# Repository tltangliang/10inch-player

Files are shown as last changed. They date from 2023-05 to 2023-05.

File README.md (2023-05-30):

# 10inch-player

A 10 inch width HiFi music player with 7.84 touchscreen.

## Features

- Simple and clear design
- Easy to use
- Hi-Res DSD support
- AirPlay and Bluetooth support
- Low cost
- Low power use

## Introduction

I have an old set of Denon speakers that can only play CDs and tapes, which is outdated. This has inspired me to come up with an idea. 

I plan to use Volumio as a digital playback system and hope that the appearance is as good-looking as possible, while keeping the cost low.

Volumio support AirPlay and Bluetooth. That's perfect. Alternatively, I can use piCorePlayer or Moode Audio Player instead.

This is the effect of placing the DIY finished product next to the Denon speaker. It looks pretty durable, doesn't it?

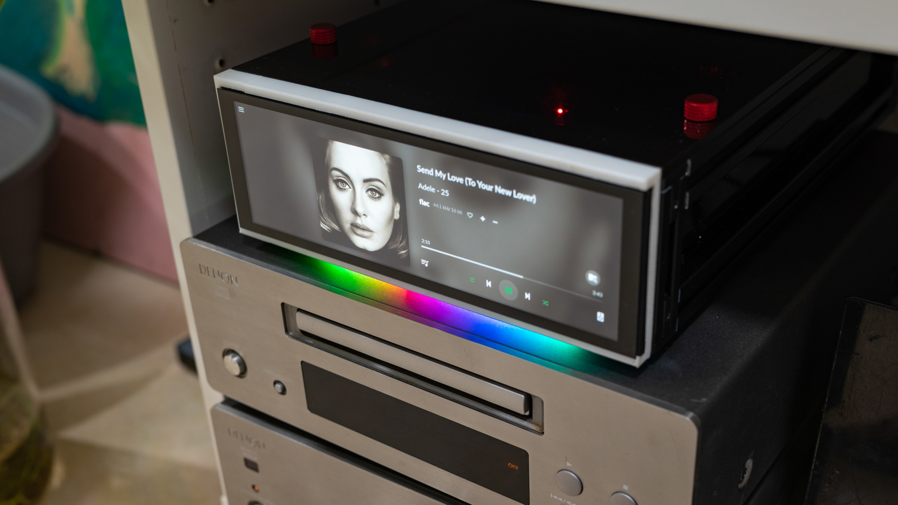
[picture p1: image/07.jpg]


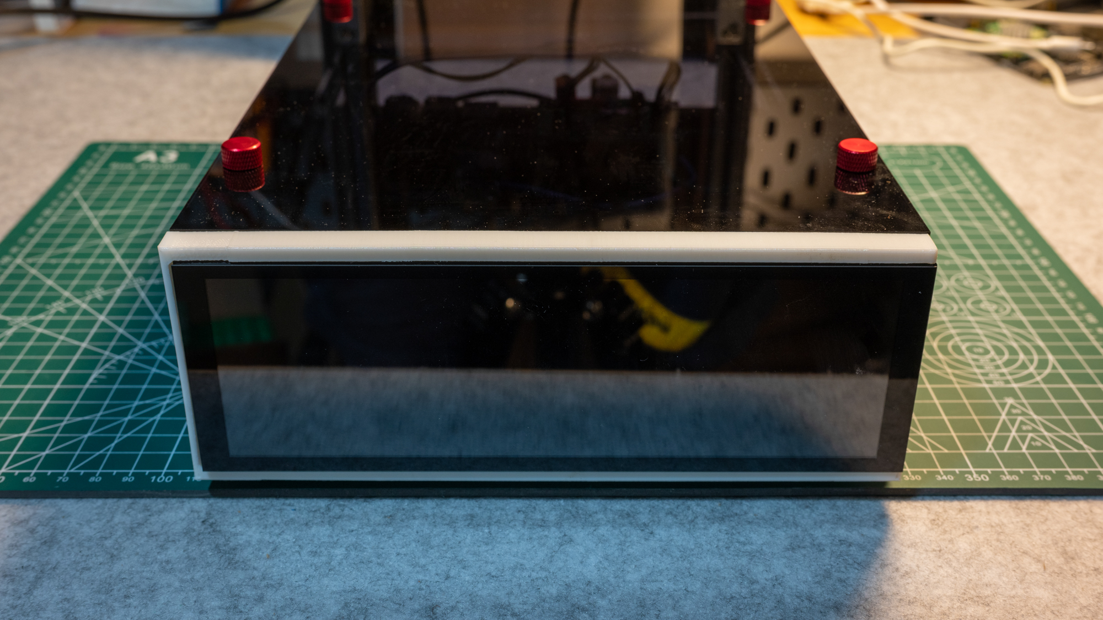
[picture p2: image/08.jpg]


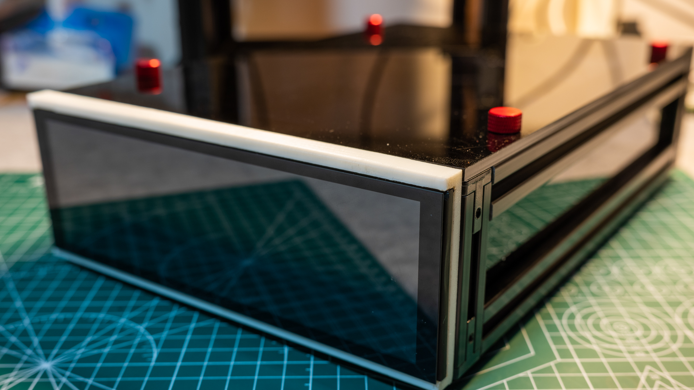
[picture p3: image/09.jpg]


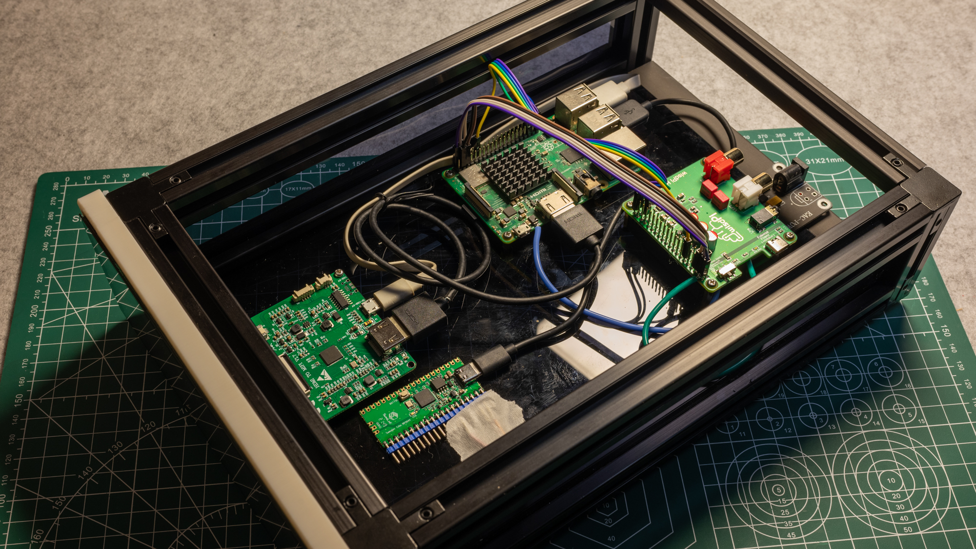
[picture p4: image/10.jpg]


## System Description

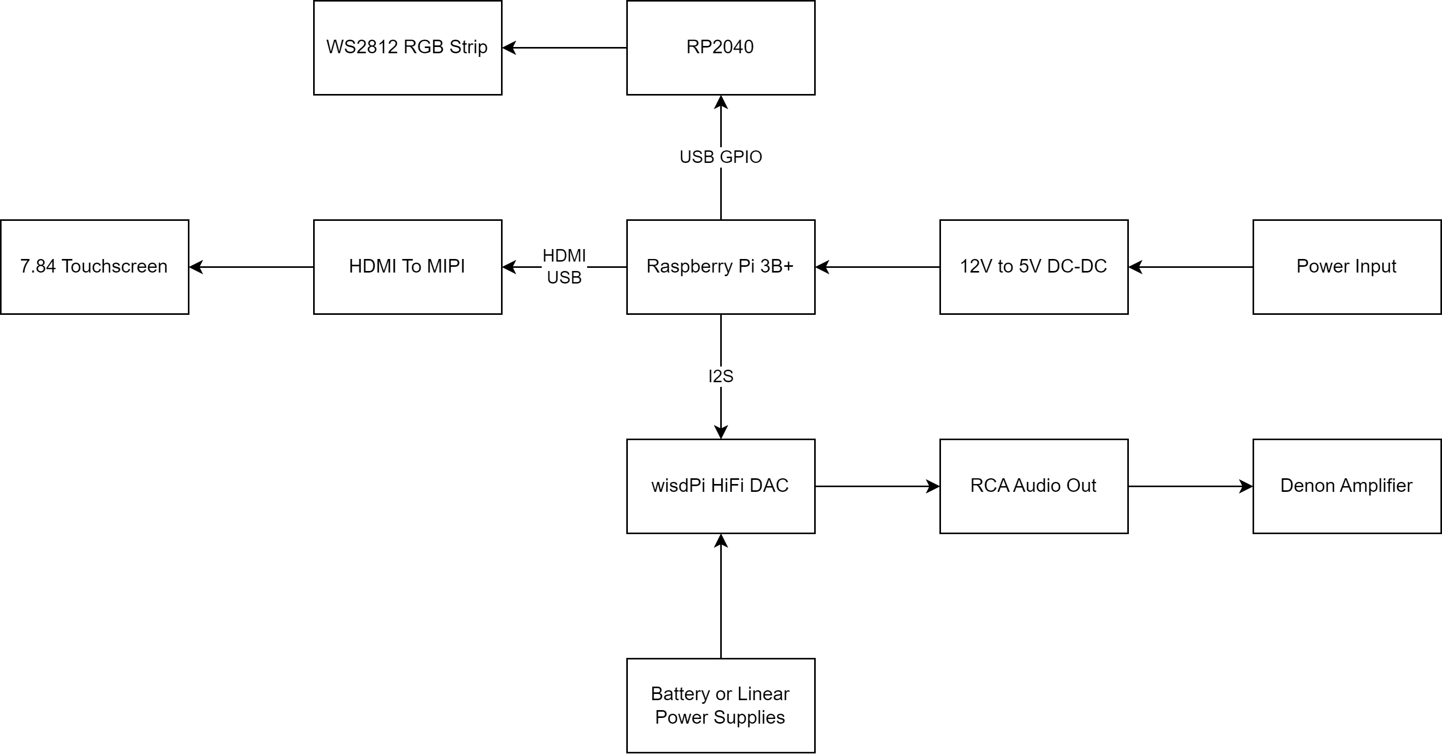
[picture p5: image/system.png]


## Rendering

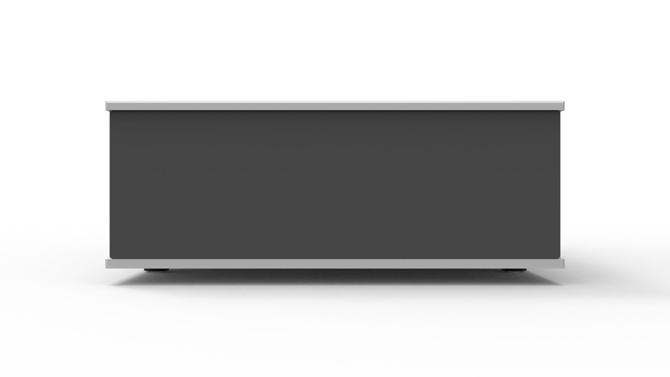
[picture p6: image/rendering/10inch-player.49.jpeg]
10inch HiFi Player :size=400x


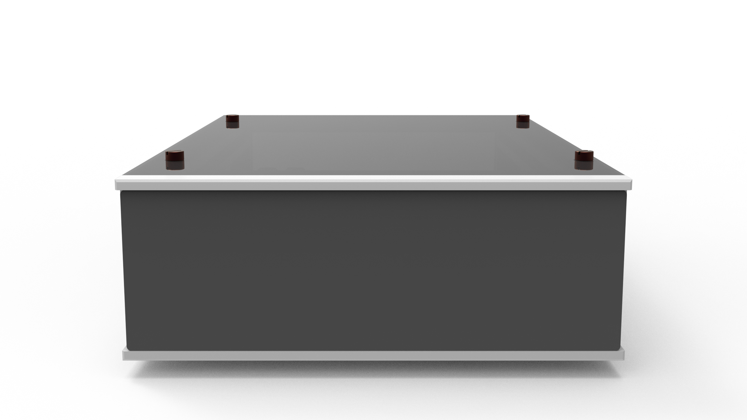
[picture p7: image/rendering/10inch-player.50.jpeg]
10inch HiFi Player :size=400x


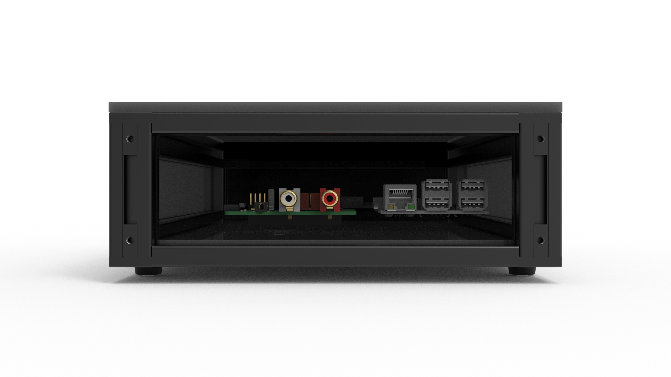
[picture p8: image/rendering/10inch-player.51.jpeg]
10inch HiFi Player :size=400x


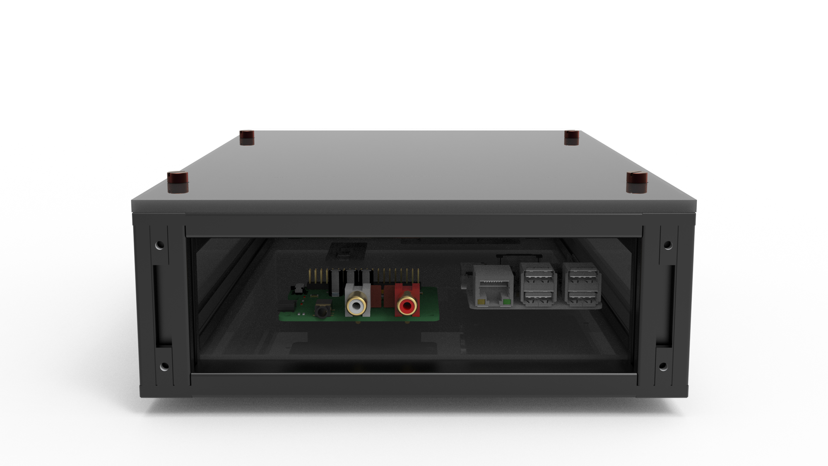
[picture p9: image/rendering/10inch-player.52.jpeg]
10inch HiFi Player :size=400x


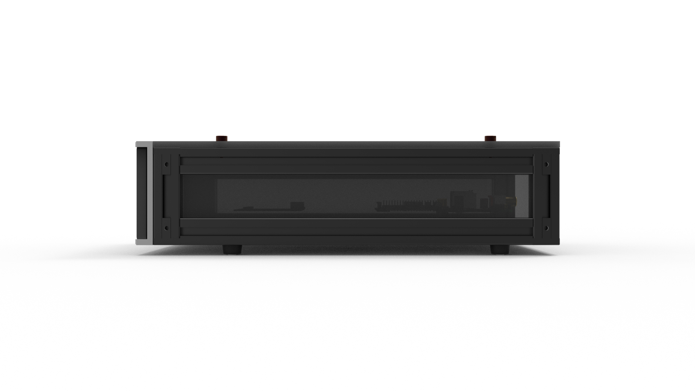
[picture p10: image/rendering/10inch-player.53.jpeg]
10inch HiFi Player :size=400x


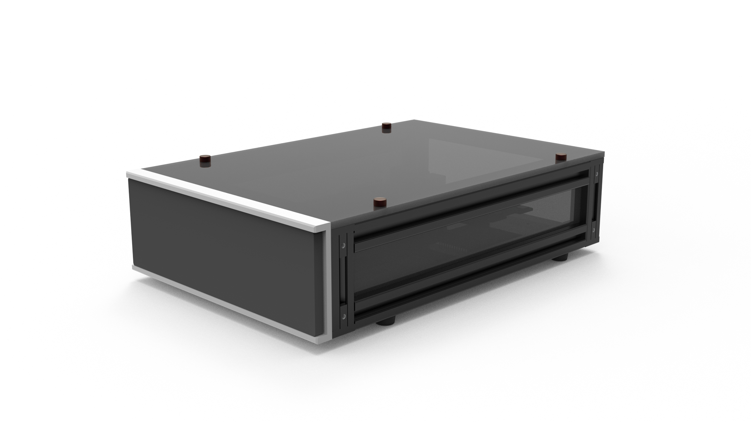
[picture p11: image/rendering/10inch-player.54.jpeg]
10inch HiFi Player :size=400x


## Case

The 10inch-Player case is made up of three materials: aluminum profile, acrylic, and 3D printed parts, along with some screws and foot pads.

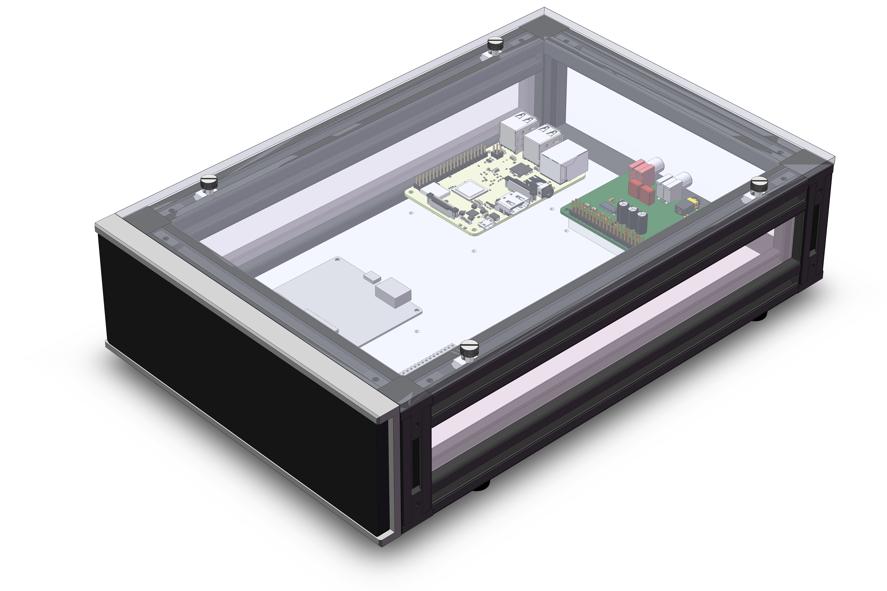
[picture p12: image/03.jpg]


## Exploded-view

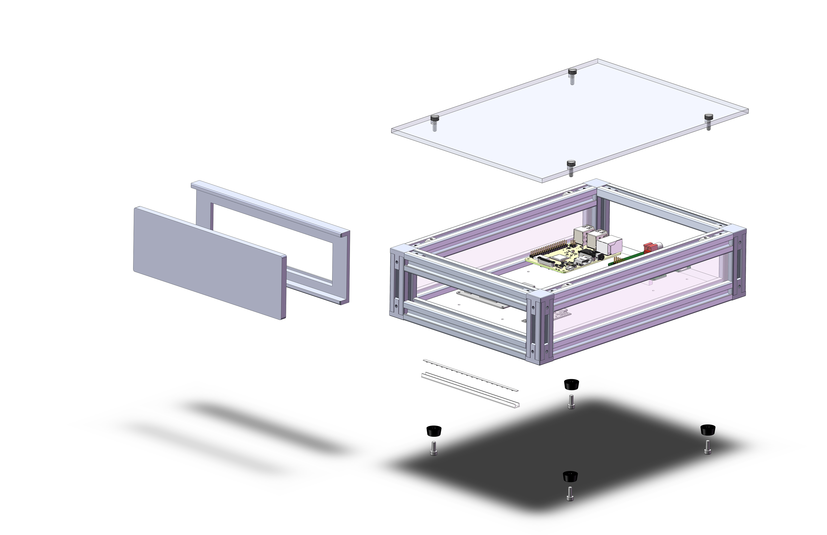
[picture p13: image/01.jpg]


## 7.84 Touchscreen

Purchase Link: [https://store.wisdpi.com/products/7-84inch-ips-long-strip-capacitive-touch-screen-lcd-400-1280-hdmi-ips-toughened-glass-cover-support-raspberry-pi](https://store.wisdpi.com/products/7-84inch-ips-long-strip-capacitive-touch-screen-lcd-400-1280-hdmi-ips-toughened-glass-cover-support-raspberry-pi)

At first I wanted to choose the waveshare screen, but then I found that the waveshare screen was not suitable for this structure and could not be used. Then I found this touchscreen from wisdPi. They use the same software. And this screen panel and driver board is independent, more suitable for diy installation

The 7.84-inch touch screen is glued to the 3D-printed bracket and then slid into the aluminum profile for fixation.

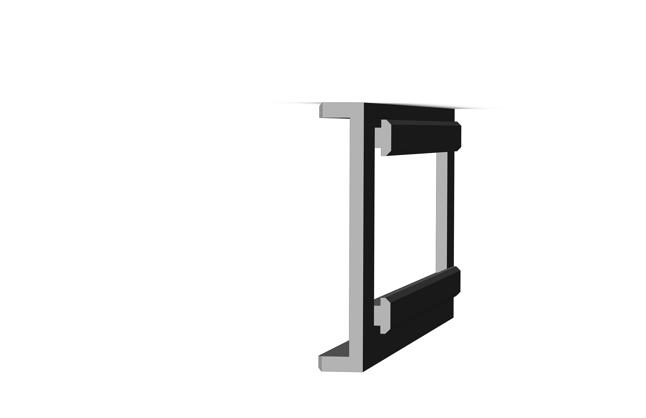
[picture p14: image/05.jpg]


## Internal circuit board

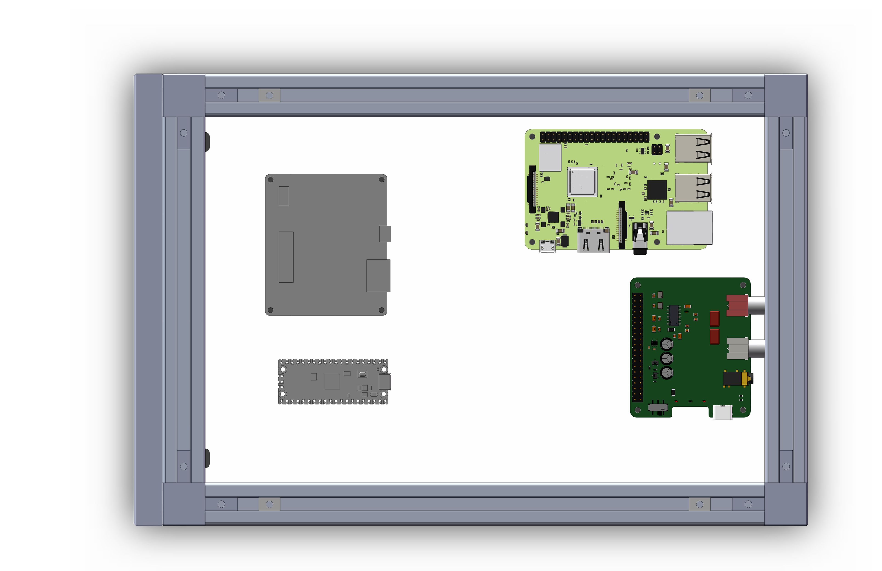
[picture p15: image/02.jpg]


### HDMI to MIPI board

This is the driver board for 7.84 LCD. It's a part of 7.84 Touchscreen.

### Raspberry Pi 3B+
For Volumio, I think RPi 3B+ is more suitable because it is much cheaper, has sufficient performance, and supports Bluetooth and 5G Wifi.

### wisdPi HiFi DAC 

Purchase Link: [https://www.amazon.com/wisdPi-Raspberry-PCM5122-Reduction-External/dp/B0C3CMCM7V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](https://www.amazon.com/wisdPi-Raspberry-PCM5122-Reduction-External/dp/B0C3CMCM7V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)

There are many HiFi DACs, but I choose the one from wisdPi.

This HAT has an active power noise reduction function, and I can use a cheaper power adapter.

Also it has an external power interface, next I will try to use a low power linear power supply to power the dac alone, which is cheaper than using a linear power supply to power the whole system. Also I can try to power the DAC directly with a battery.

### Sumolink Erhu RP2040

Purchase Link: [https://www.temu.com/sumolink-erhu-rp2040-pico-like-mcu-board-based-on-raspberry-pi-rp2040-chip-dual-core-arm-cortex-m0-processor-up-to-133-mhz-onboard-4mb-flash-usb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](https://www.temu.com/sumolink-erhu-rp2040-pico-like-mcu-board-based-on-raspberry-pi-rp2040-chip-dual-core-arm-cortex-m0-processor-up-to-133-mhz-onboard-4mb-flash-usb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)

To control WS2812 RGB strip and the power next step, I use an rp2040 mcu.

I used the rp2040 instead of the Raspberry Pi gpio because it was difficult for me to modify the volumio. And using an external mcu gives me more freedom and I can control more devices, such as the LCD brightness, RPi power on or power off.

Just because the price, I choose Sumolink Erhu RP2040, you can use any rp2040 mcu board as the same.

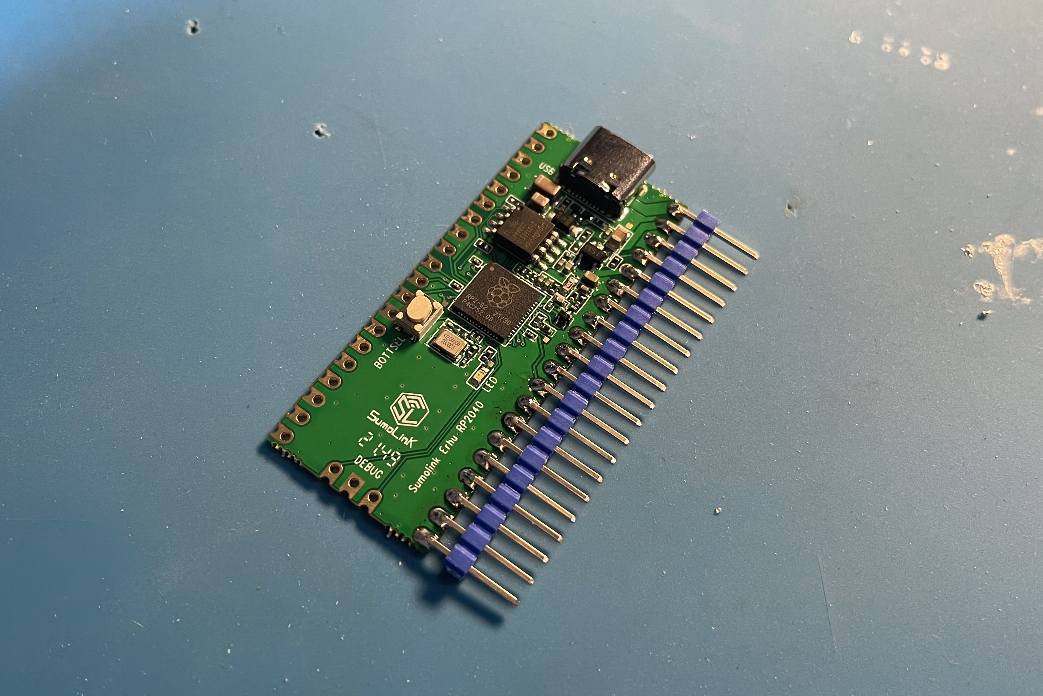
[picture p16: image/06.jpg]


# Buy me a coffee

If you find my projects helpful or interesting, could you buy me a coffee. Your support will help me continue creating new and innovative projects, as well as provide exclusive access to my content.

Buy Me A Coffee :size=50x (https://www.buymeacoffee.com/tltangliang)

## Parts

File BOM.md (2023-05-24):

# 7.84 Touchcreen Player BOM

| Title | Parameter | Quantity | |
| --- | --- | --- | --- |
| aluminum extrusion 260mm | 2020T Black  | 4 | |
| aluminum extrusion 62mm| 2020T Black | 4 | |
| aluminum extrusion 170mm | 2020T Black | 2 | |
| aluminum extrusion 170mm | 1020V Black | 2 | |
| aluminum extrusion connection | 2020 3D | 8 | |
| acrylic top | Thickness 5 mm | 1 | |
| acrylic bottom | Thickness 5 mm | 1 | |
| acrylic side | Thickness 5 mm | 2 | |
| sider nut | 2020 M4| 8 | |
| aluminum knurled screws | M4 x 12mm Dark Red | 4 | |
| rubber feet | 15-13-7 M4 | 4 | |
| rubber feet screws |  M4 x 10mm | 4 | |
| LCD mount | 3D print | 1 | |
| LCD 7.84 Touch | 400x1280 IPS  | 1 | |
| LCD driver board | HDMI to MIPI | 1 | |
| HiFi DAC HAT | wisdPi HiFi DAC | 1 | |
| MCU | Sumolink Erhu RP2040 | 1 | |
| RGB strip | WS28128 3MM 100LEDS/m 13cm long | 1 | |
| DC-DC Module | 12V to 5V | 1 | optional |
| Raspberry Pi | Pi 3B+ | 1 | |

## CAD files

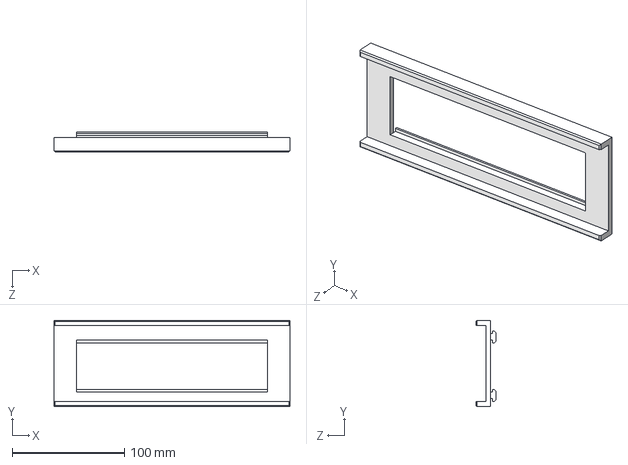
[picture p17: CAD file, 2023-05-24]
01.structure/3D print LCD mount/LCD mount.STEP
210.0 x 76.7 x 17.9 mm

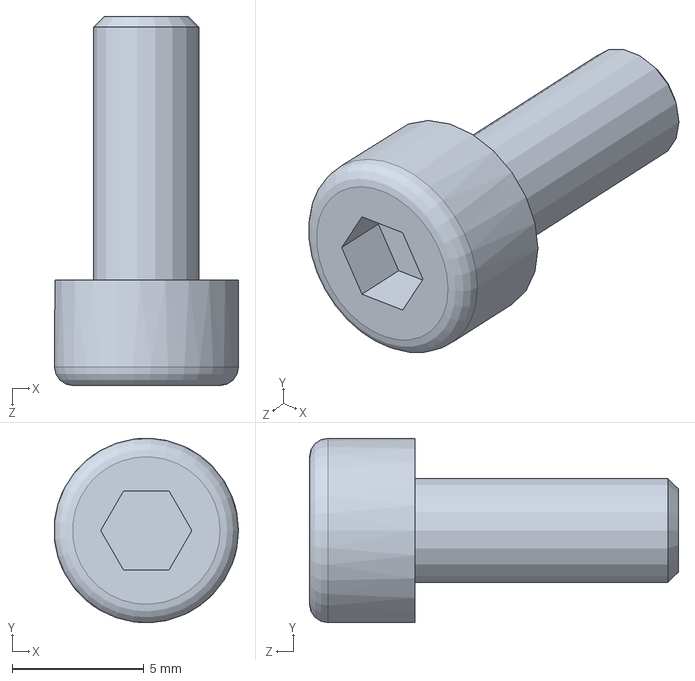
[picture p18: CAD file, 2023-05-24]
01.structure/M4 x 10 srew.SLDPRT
6.98 x 6.99 x 14.0 mm

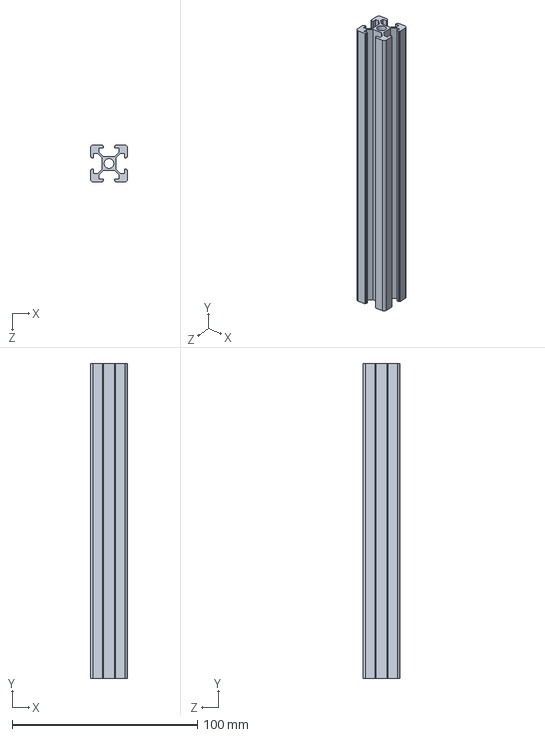
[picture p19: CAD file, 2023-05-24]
01.structure/2020 W 170mm.SLDPRT
20.0 x 170.0 x 20.0 mm

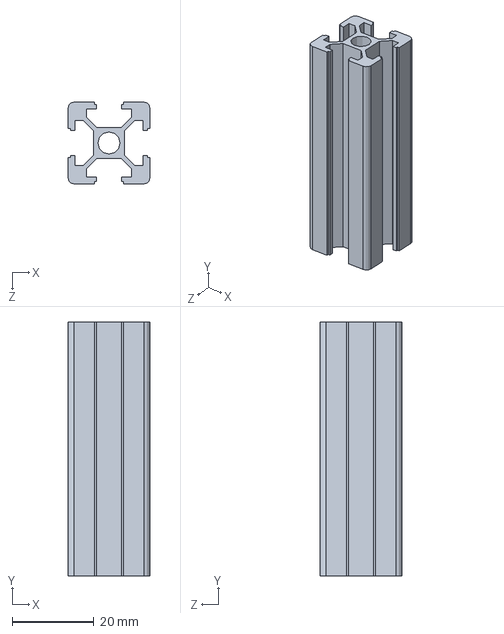
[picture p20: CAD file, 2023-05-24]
01.structure/2020 H 62mm.SLDPRT
20.0 x 62.0 x 20.0 mm

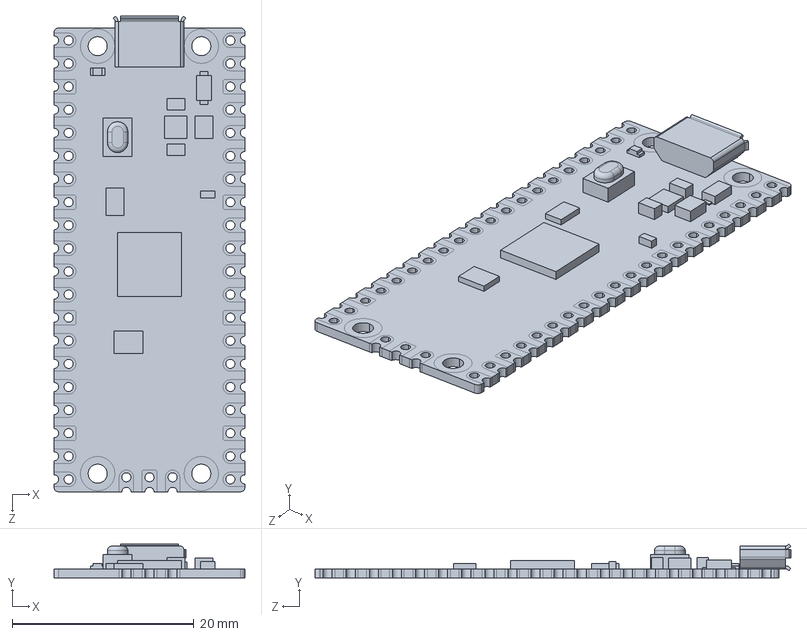
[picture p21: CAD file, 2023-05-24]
01.structure/RPI Pico-R3.SLDPRT
21.0 x 3.73 x 52.3 mm

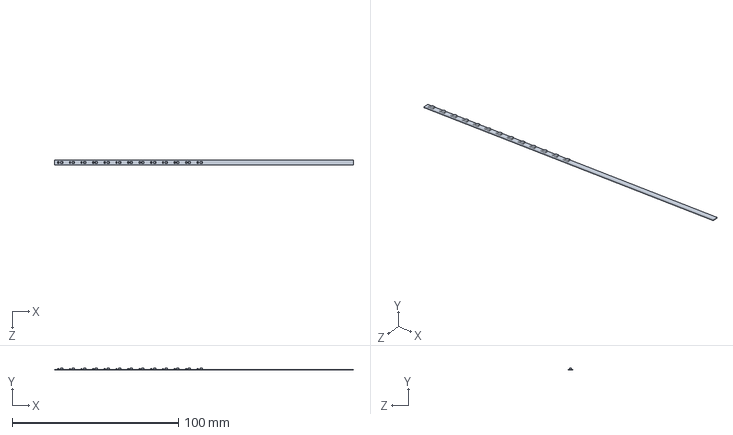
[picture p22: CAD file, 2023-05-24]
01.structure/3mm RGB Strip.SLDPRT
180.0 x 1.50 x 3.00 mm

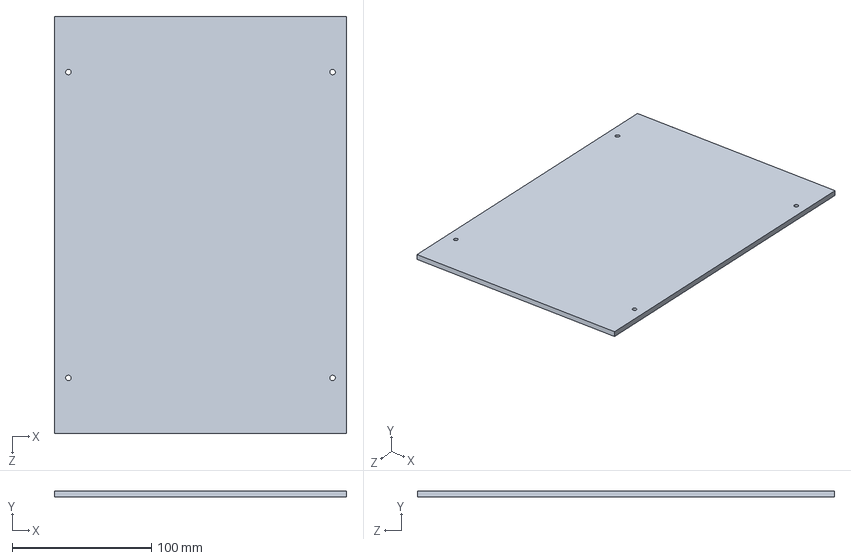
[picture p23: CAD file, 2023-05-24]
01.structure/acrylic top.SLDPRT
210.0 x 4.65 x 300.0 mm

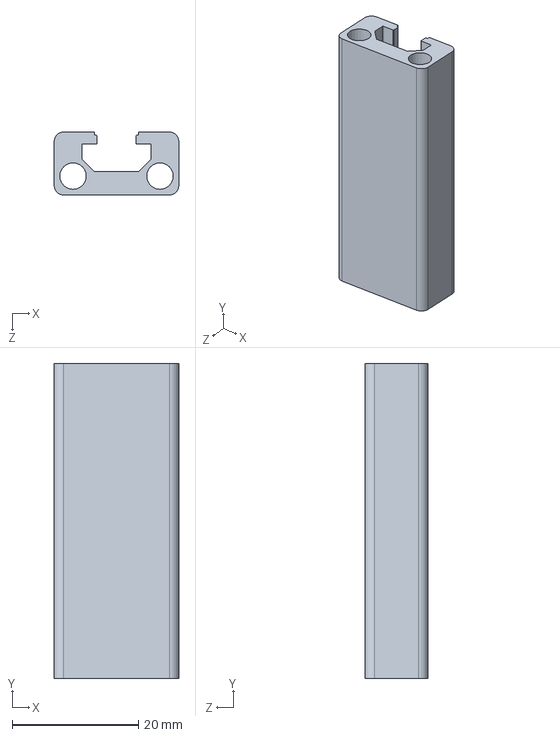
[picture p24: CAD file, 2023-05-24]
01.structure/1020 W 170mm.SLDPRT
19.8 x 50.0 x 10.0 mm

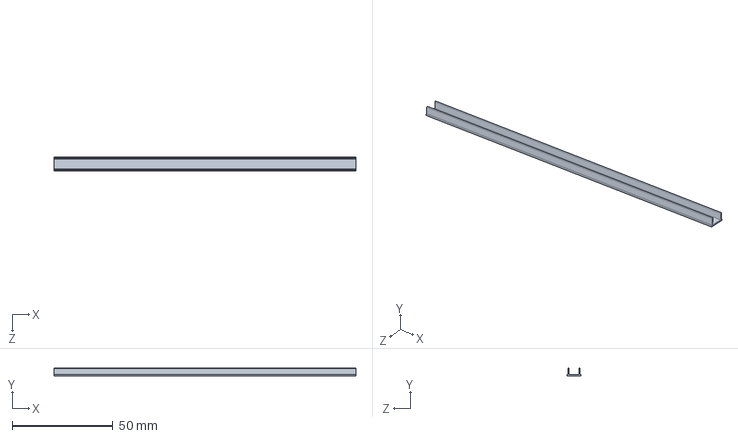
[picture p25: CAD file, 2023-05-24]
01.structure/semi-transparent Hard rubber strip 130mm.SLDPRT
150.0 x 4.00 x 7.00 mm

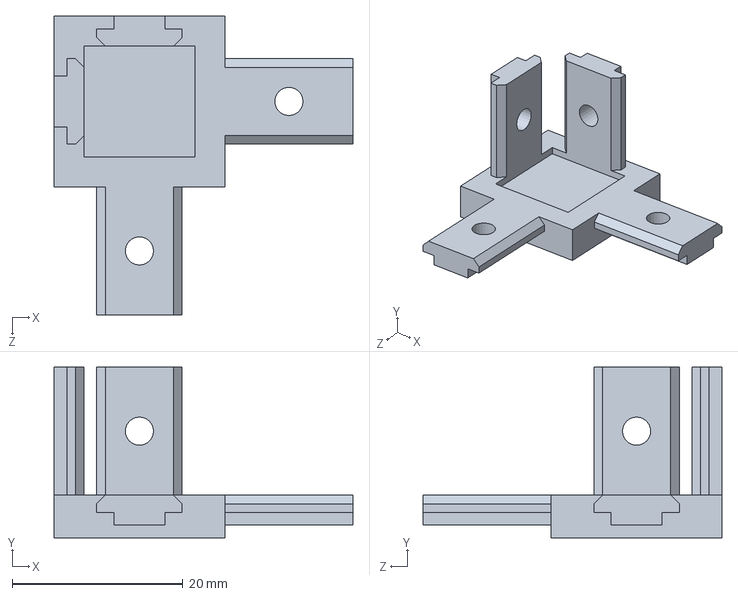
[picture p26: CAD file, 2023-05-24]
01.structure/2020 3D connection.SLDPRT
35.0 x 20.0 x 35.0 mm

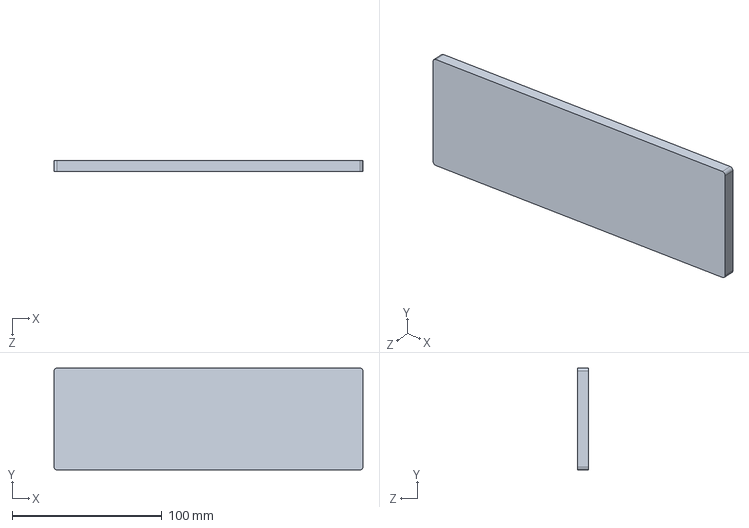
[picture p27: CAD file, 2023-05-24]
01.structure/LCD 7.84 IPS.SLDPRT
206.0 x 68.0 x 7.00 mm

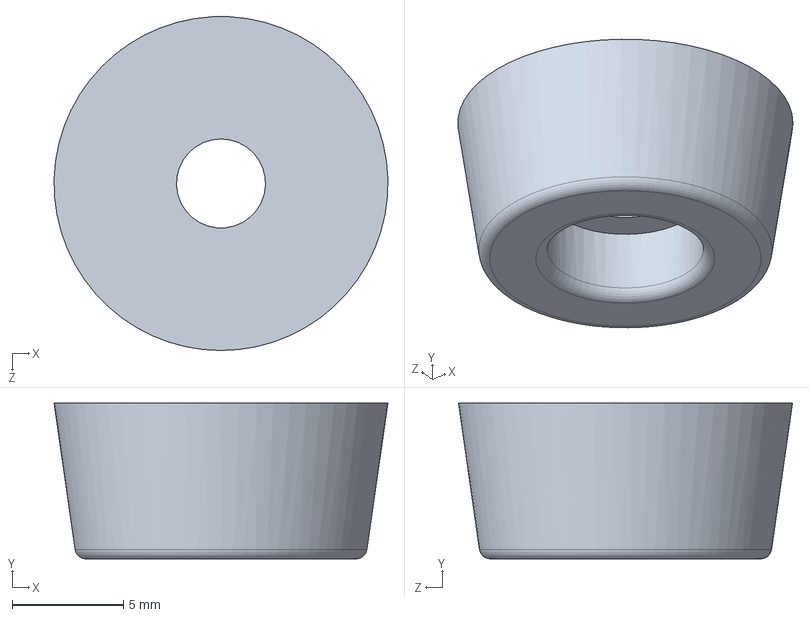
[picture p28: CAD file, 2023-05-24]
01.structure/15-13-7_M4 foot.SLDPRT
15.0 x 7.00 x 15.0 mm

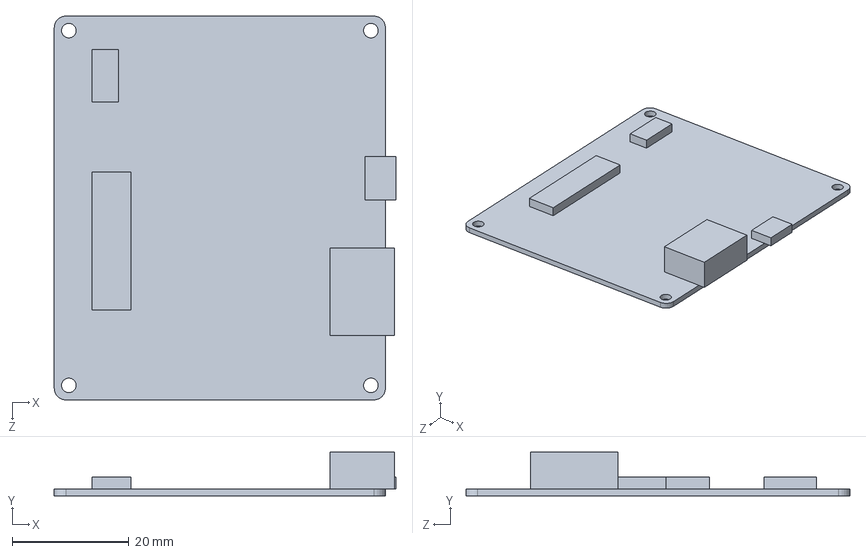
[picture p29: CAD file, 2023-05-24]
01.structure/7.84 LCD Driver.SLDPRT
58.4 x 7.50 x 65.7 mm

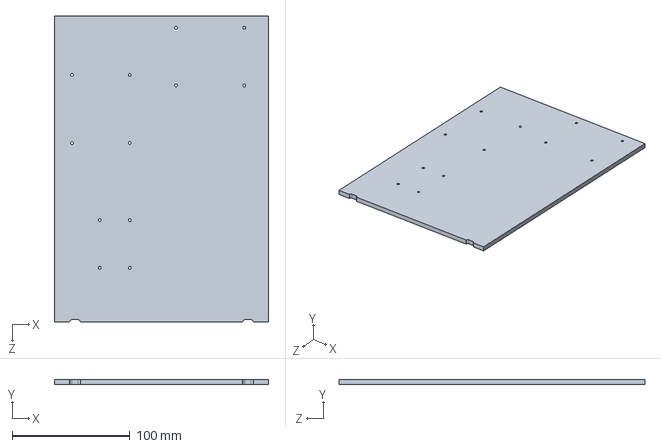
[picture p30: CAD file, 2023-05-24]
01.structure/acrylic bottom.SLDPRT
182.0 x 4.65 x 260.0 mm

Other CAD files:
01.structure/LCD mount.SLDPRT
01.structure/acrylic side.SLDPRT
01.structure/2020 D 260mm.SLDPRT
01.structure/2020 slider nut M4.SLDPRT
01.structure/3D print LCD mount/LCD mount.STL

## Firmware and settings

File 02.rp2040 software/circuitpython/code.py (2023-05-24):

# SPDX-FileCopyrightText: 2021 Kattni Rembor for Adafruit Industries
#
# SPDX-License-Identifier: MIT

"""
NeoPixel example for Pico. Displays a rainbow on the NeoPixels.

REQUIRED HARDWARE:
* RGB NeoPixel LEDs connected to pin GP0.
"""
import time
import board
from rainbowio import colorwheel
import neopixel

# Update this to match the number of NeoPixel LEDs connected to your board.
num_pixels = 13
pixel_pin = board.GP0

pixels = neopixel.NeoPixel(pixel_pin, num_pixels, auto_write=False)
pixels.brightness = 0.5



def rainbow(speed):
    for j in range(255):
        for i in range(num_pixels):
            pixel_index = (i * 256 // num_pixels) + j
            pixels[i] = colorwheel(pixel_index & 255)
        pixels.show()
        time.sleep(speed)


while True:
    rainbow(0.01)
